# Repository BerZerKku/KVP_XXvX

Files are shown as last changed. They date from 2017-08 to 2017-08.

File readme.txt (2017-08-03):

Плата KVP
Сделана в OrCAD 16.6-2015-S073.

///////
03v5
Предназначена для использования в ОПТИКЕ и АВАНТах К400, РЗСК, Р400М сделанными в новом варианте. Используется совместно с BVP не ранее 04v2, если не нужна цифровая ретрансляция. И не ранее 04v3 если нужна.

Изменения:
Исправлены контактные площадки на супрессорах.
Дискретные входы сделаны с возможностью выбора перемычками 24/110/220В.

Код ПП: 3.140.490
Код КВП К400 : 2.140.808 (РЗСК)
Код КВП Р400 : 2.140.xxx
Код КВП Р400М: 2.140.xxx

Стэк:
35мкм  TOP 
1.5мм e=4.1 FR-4
35мкм  BOTTOM

Вариант Р400М:
отсутствуют: цифровая ретрансляция, выходы ком.ПРД/ПРМ, вход ПУСК, выход "Предупреждение".

Вариант Р400:
отсутствуют: цифровая ретрансляция, выходы ком.ПРД/ПРМ, вход ПУСК

Вариант К400 (РЗСК):
плата запаивается полностью.

//////
03v4
Предназначена для использования в ОПТИКЕ и АВАНТах К400, РЗСК, Р400М сделанными в новом варианте. Используется совместно с BVP не ранее 04v2, если не нужна цифровая ретрансляция. И не ранее 04v3 если нужна.

Изменения:
Добавлены дополнительные переключатели на ЛС/ТМ для выбора 485/422 интерфейса. При этом в 422 интерфейсе выход начинает работать полноценно, в 485 лог.1 формируется за счет подтяжек. 
Подтяжки на 485/422 интерфейсе перенесены на входы A/B и их номинал изменен с 470 Ом на 270 Ом. 
Последовательные защитные резисторы на интефейсах изменены с 10 на 5.1 Ом.
Разъем DIN изменен на 3-х рядный.

Код ПП: 3.140.015
Код ПП в сборе: 2.140.174

Стэк:
18мкм  TOP 
1.5мм e=4.5 FR-4
18мкм  BOTTOM

Основной вариант (Р400М):
отсутствуют: цифровая ретрансляция, выходы ком.ПРД/ПРМ, вход ПУСК, выход "Предупреждение".

Вариант Р400:
добавлен выход "Предупреждение"

Вариант К400 (РЗСК):
плата запаивается полностью.

////
03v3
Предназначена для использования в ОПТИКЕ и АВАНТах К400, РЗСК, Р400М 
сделанными в новом варианте.
Используется совместно с BVP не ранее 04v2, если не нужна цифровая
ретрансляция. И не ранее 04v3 если нужна.

Изменения:
Переделана цивровая ретрансляция. Сделан чистый 422 интерфейс и добавлен
сигнал управления.
Терминаторы 120 и 51Ом изменены на 240Ом.

Основной вариант (Р400М):
отсутствуют: цифровая ретрансляция, выходы ком.ПРД/ПРМ, вход ПУСК.

Вариант Р400:
добавлен выход "Предупреждение"

Вариант К400 (РЗСК):
плата запаивается полностью.

Недостатки:
Резисторы подтяжки стоят на выводах X/Y, что при переключении на 422 убирает
подтяжки с выводов A/B и оставляет вход 422 интерфейса без подтяжки. 
Вообще дуплекс/полудуплекс сделан хреново.
Место резисторов можно поставить предохранители.

!!!
На данный момент входы управления запаиваются только под 24.
Номиналы резисторов для других напряжений см. в РЭ.
!!!

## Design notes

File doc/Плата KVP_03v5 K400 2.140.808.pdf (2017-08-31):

п.5

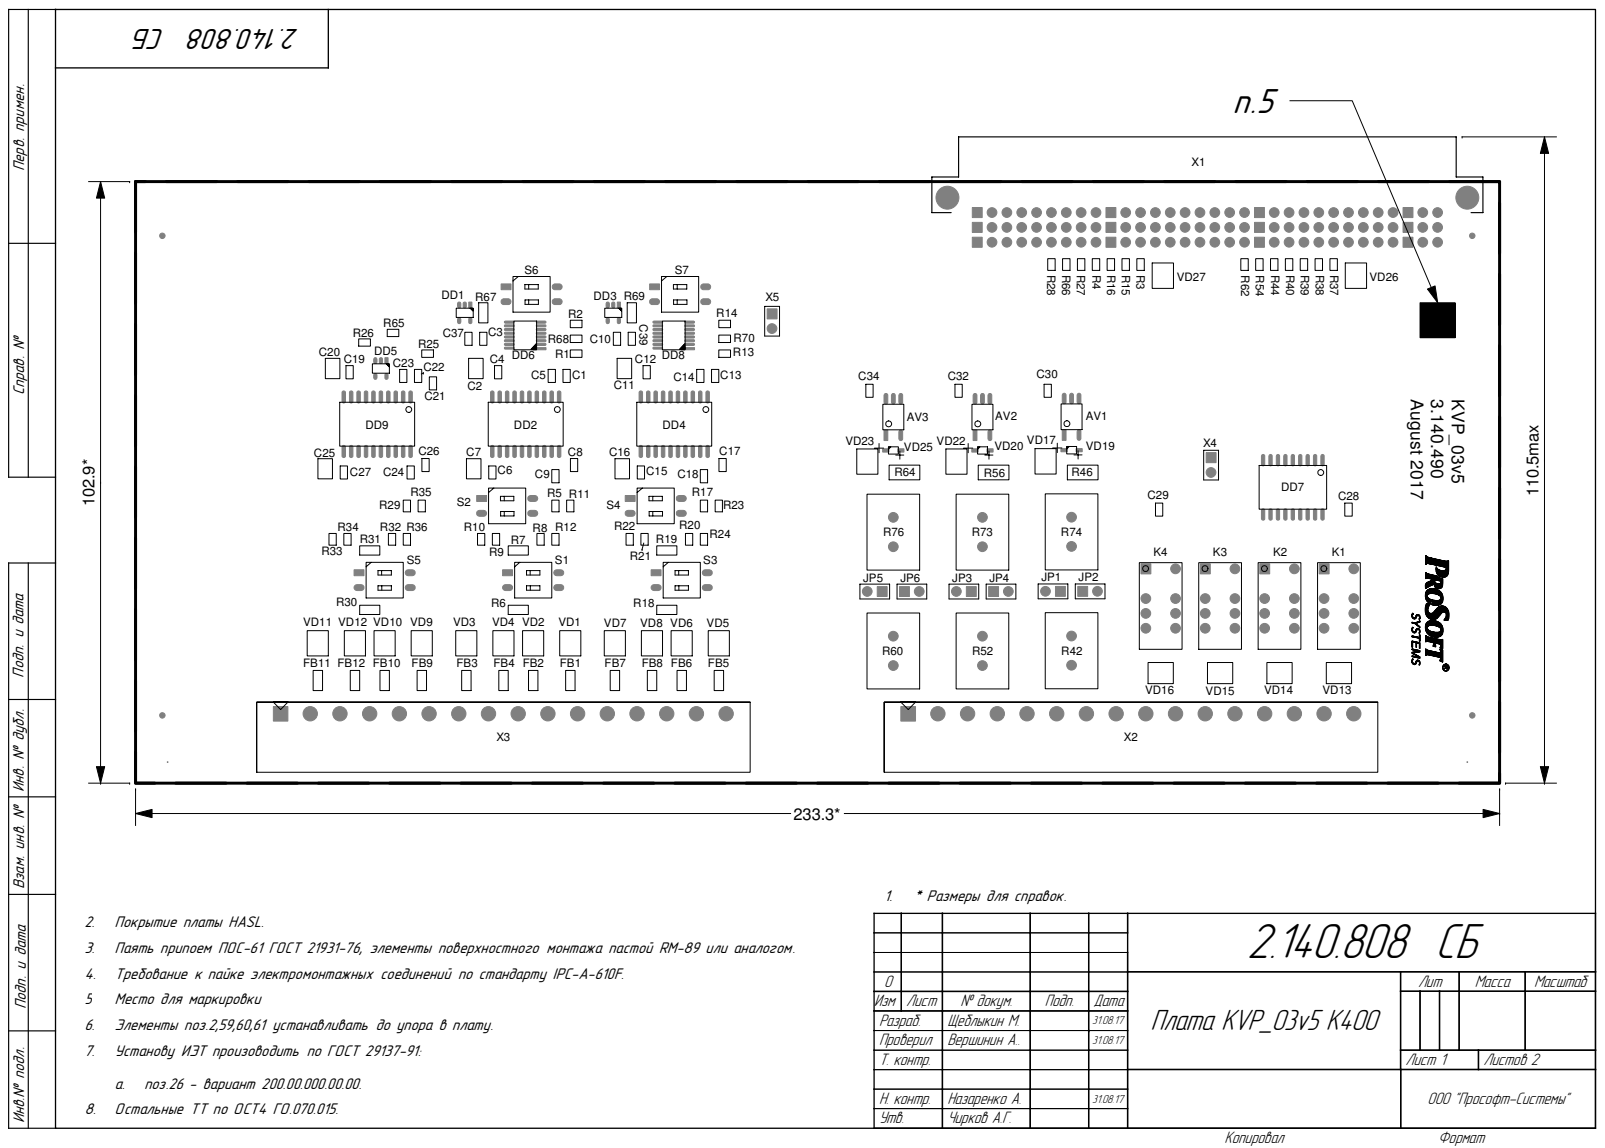
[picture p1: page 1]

Инв.№ подл. Подп. и дата Взам. инв. № Инв. № дубл. Подп. и дата Справ. № Перв. примен. R60 R52 R46

2. Покрытие платы HASL.
3. Паять припоем ПОС-61 ГОСТ 21931-76, элементы поверхностного монтажа пастой RM-89 или аналогом.
4. Требование к пайке электромонтажных соединений по стандарту IPC-A-610F.
5 Место для маркировки
6. Элементы поз.2,59,60,61 устанавливать до упора в плату.
7. Установу ИЭТ произоводить по ГОСТ 29137-91:

0 | | | | | Ïëàòà KVP_03v5 K400 | Ëèò | Ìàññà | Ìàñøòàá
Èçì | Ëèñò | ¹ äîêóì. | Ïîäï. | Äàòà
Ðàçðàá. | | Ùåáëûêèí Ì. | | 31.08.17
Ïðîâåðèë | | Âåðøèíèí À.. | | 31.08.17
Ò. êîíòð. | | | | | Ëèñò 1 | Ëèñòîâ 2

a. поз.26 - вариант 200.00.000.00.00.
8. Остальные ТТ по ОСТ4 ГО.070.015.

Í. êîíòð. | Íàçàðåíêî À. | 31.08.17
Óòâ. | ×èðêîâ À.Ã.

ÎÎÎ "Ïðîñîôò-Ñèñòåìû"

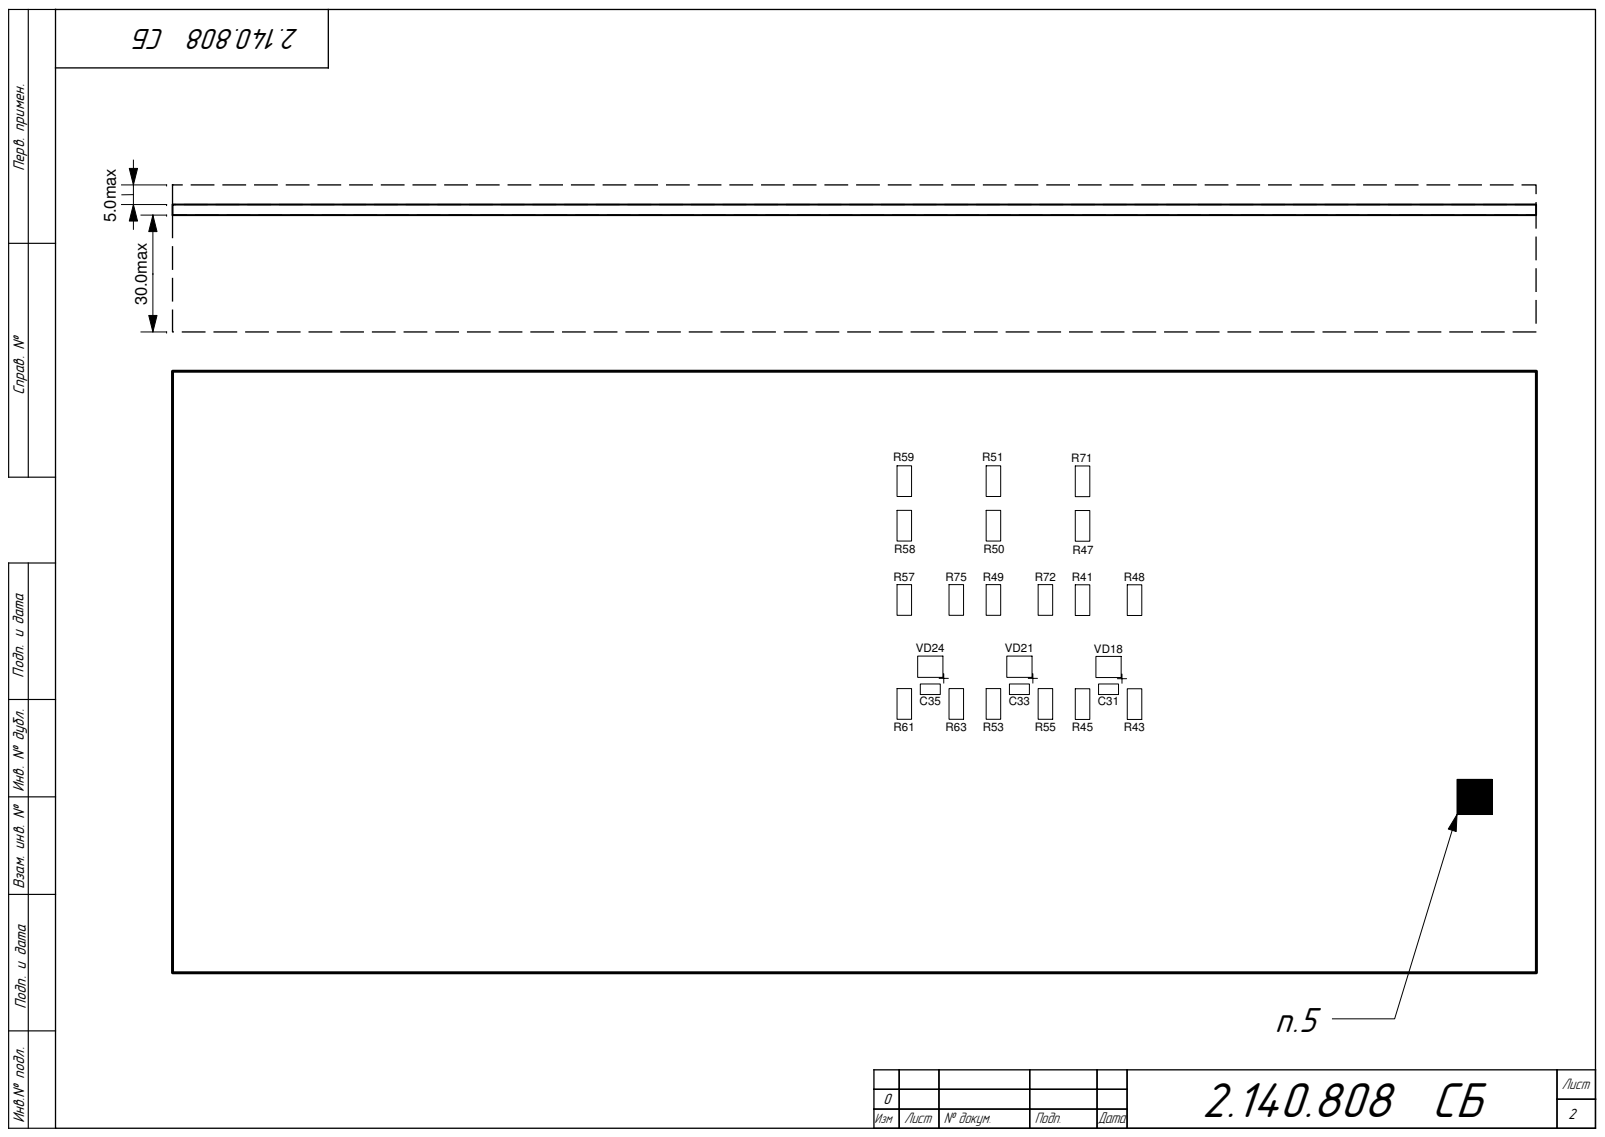
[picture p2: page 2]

Инв.№ подл. Подп. и дата Взам. инв. № Инв. № дубл. Подп. и дата Справ. № Перв. примен.

Напечатано: 31 августа 2017 г. 11:40:04, Щеблыкин Михаил Владимирович
Поз. | Наименование | Корпус | Кол. | Поз. по Э3 | Примечание
| Детали
1 | [3.140.490] Печатная плата KVP_03v5 | | 1
| Прочее
| Реле
2 | [G6S224DC] Реле G6S224DC 24VDC 2 Form C 0.5A/125VAC Omron | DIP8 | 4 | K1-K4
| Конденсаторы
6 | [0805-X7R-50V-0.1u F-10%] [+]Чип-конденсатор 0805 X7R 50V 0.1uF 10% | 0805 | 22 | C1, C3, C4, C6, C9, C10, C12, C13, C15, C18, C19, C21, C22, C24, C27-C30, C32, C34, C37, C39
7 | [1210-X7R-25V-10uF -10%] [+] Чип-конденсатор 1210 X7R 25V 10uF 10% | 1210 | 6 | C2, C7, C11, C16, C20, C25
8 | [0805-X7R-50V-0.01 uF-10%] Чип-конденсатор 0805 X7R 50V 0.01uF 10% | 0805 | 6 | C5, C8, C14, C17, C23, C26
9 | [1206-X7R-50V-0.1u F-10%] Чип-конденсатор 1206 X7R 50V 0.1uF 10% | 1206 | 3 | C31, C33, C35
| Дроссели, фильтры, катушки индуктивности
15 | [BLM31PG601SN1] Ферритовый фильтр BLM31PG601SN1 600Ом 1.5А 1206 Murata | 1206 | 12 | FB1-FB12

2.140.808

| Лист | № докум | Подп. | Дата
Разраб. | Щеблыкин М.В. | | 01.08.2017 | Плата KVP_03v5 K400 (Плата KVP_03v5 K400) | Лит. | Лист | Листов
Провер. | Вершинин А.С. | | 01.08.2017 | | | 1 | 5
Т.контр. | Бокова Т.И. | | 01.08.2017 | | Прософт-Системы
Н.контр. | Назаренко А.Н. | | 01.08.2017
Утв. | Чирков А.Г. | | 01.08.2017

| Резисторы
19 | [0805-10K-5%] Чип-резистор 0805 10K 5% | 0805 | 9 | R1, R2, R13, R14, R25, R26, R65, R68, R70
20 | [0805-100-5%] Чип-резистор 0805 100 5% | 0805 | 7 | R3, R4, R15, R16, R27, R28, R66
21 | [0805-5.1-5%] Чип-резистор 0805 5.1 5% | 0805 | 12 | R5, R8-R10, R17, R20-R22, R29, R32-R34
22 | [1206-240-5%] Чип-резистор 1206 240 5% | 1206 | 6 | R6, R7, R18, R19, R30, R31
23 | [0805-270-5%] Чип-резистор 0805 270 5% | 0805 | 6 | R11, R12, R23, R24, R35, R36
24 | [0805-6.2K-5%] Чип-резистор 0805 6.2K 5% | 0805 | 4 | R37-R40
25 | [2010-240-5%] Чип-резистор 2010 240 5% | 2010 | 6 | R41, R48, R49, R57, R72, R75
26 | [SQM-5W-5.1K-5%] Резистор SQM-5W 5.1K 5% | LEAD-2 | 6 | R42, R52, R60, R73, R74, R76
27 | [2010-300-5%] Чип-резистор 2010 300 5% | 2010 | 6 | R43, R45, R53, R55, R61, R63
28 | [0805-2K-5%] Чип-резистор 0805 2K 5% | 0805 | 3 | R44, R54, R62
29 | [2010-100-5%] Чип-резистор 2010 100 5% | 2010 | 3 | R46, R56, R64
30 | [2010-560-5%] Чип-резистор 2010 560 5% | 2010 | 3 | R47, R50, R58
31 | [2010-510-5%] Чип-резистор 2010 510 5% | 2010 | 3 | R51, R59, R71
32 | [1206-0] Чип-резистор 1206 0 | 1206 | 2 | R67, R69

2.140.808

Лист

2 Изм | Лист | № докум | Подп. | Дата

| Микросхемы
38 | [ACPL-M50L-500E] Микросхема | SO5 | 3 | AV1-AV3
| ACPL-M50L-500E SO5 Avago
39 | [SN74LVC1G14DBV] Микросхема SN74LVC1G14DBV SOT23-5 TI | SOT23-5 | 3 | DD1, DD3, DD5
40 | [ADM2587EBRWZ] Микросхема ADM2587EBRWZ SOICW20 AD (level:3) | SOICW2 0 | 3 | DD2, DD4, DD9
41 | [IDTQS3257QG] Микросхема IDTQS3257QG QSOP16 IDT | QSOP16 | 2 | DD6, DD8
42 | [ULN2803ADW] Микросхема ULN2803ADW SOIC18 TI | SOIC18 | 1 | DD7
| Диоды,светодиоды,супрессоры,стабилитроны
46 | [SM6T6V8CA] Диод SM6T6V8CA SMB STM | SMB(DO -214 | 13 | VD1-VD12, VD27
47 | [P6SMB300CA] Диод P6SMB300CA | SMB(DO -214 | 4 | VD13-VD16
48 | [SM6T6V8A] Диод SM6T6V8A SMB STM | SMB(DO -214 | 3 | VD17, VD20, VD23
49 | [SM6T18A] Диод SM6T18A | SMB(DO -214 | 3 | VD18, VD21, VD24
50 | [1N4148WS] Диод 1N4148WS SOD-323 | SOD323 | 3 | VD19, VD22, VD25
51 | [SM6T30CA] Диод SM6T30CA DO-214AA | SMB(DO -214 | 1 | VD26
| Переключатели, тумблеры
55 | [SmWDL-02] Переключатель SmWDL-02 | SMD4 | 7 | S1-S7
| Соединители
59 | [PLS-40] Разъем PLS-40 | 2 | 8 | JP1-JP6, X4, X5
| | | | 3 Изм
Лист | № докум | Подп. | Дата

60 | [09031966921] Соединитель, вилка DIN41612-C96MS-C1A -2 | DIN96 | 1 | X1
61 | [231-576/001-000] Вилка 1,2X1,2 шаг 5,08 мм (50 шт) | 16 | 2 | X2, X3
| | | | 4 Изм
Лист | № докум | Подп. | Дата

Лист регистрации ревизий

№ ревизии | № замененных (измененных) страниц | Дата ревизии | Краткое содержание и причина внесения изменений | Примечание
0 | вновь | 01.08.17

2.140.808

5

Лист Изм. | Лист | № докум. | Подп. | Дата

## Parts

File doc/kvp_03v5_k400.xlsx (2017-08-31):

 |  |  |  |  | Capture CIS Standard Bill Of Materials - Compressed Report
 |  |  |  |  |  | Report Created on Tuesday Aug 08 13:48:24 2017
Part Number | Description | Quantity | Ед. изм | Part Reference | Element Type | Case | Addition | Analogue
ACPL-M50L-500E | Микросхема ACPL-M50L-500E SO5 Avago | 3 | 0 | AV1-AV3 | Микросхемы | SO5
0805-X7R-50V-0.1uF-10% | [+]Чип-конденсатор 0805 X7R 50V 0.1uF 10% | 22 | 0 | C1,C3,C4,C6,C9,C10,C12,C13,C15,C18,C19,C21,C22,C24,C27-C30,C32,C34,C37,C39 | Конденсаторы | 0805
1210-X7R-25V-10uF-10% | [+] Чип-конденсатор 1210 X7R 25V 10uF 10% | 6 | 0 | C2,C7,C11,C16,C20,C25 | Конденсаторы | 1210
0805-X7R-50V-0.01uF-10% | Чип-конденсатор 0805 X7R 50V 0.01uF 10% | 6 | 0 | C5,C8,C14,C17,C23,C26 | Конденсаторы | 0805
1206-X7R-50V-0.1uF-10% | Чип-конденсатор 1206 X7R 50V 0.1uF 10% | 3 | 0 | C31,C33,C35 | Конденсаторы | 1206
SN74LVC1G14DBV | Микросхема SN74LVC1G14DBV SOT23-5 TI | 3 | 0 | DD1,DD3,DD5 | Микросхемы | SOT23-5
ADM2587EBRWZ | Микросхема ADM2587EBRWZ SOICW20 AD (level:3) | 3 | 0 | DD2,DD4,DD9 | Микросхемы | SOICW20
IDTQS3257QG | Микросхема IDTQS3257QG QSOP16 IDT | 2 | 0 | DD6,DD8 | Микросхемы | QSOP16 |  | N000353503
ULN2803ADW | Микросхема ULN2803ADW SOIC18 TI | 1 | 0 | DD7 | Микросхемы | SOIC18 |  | ULN2803AFWG
BLM31PG601SN1 | Ферритовый фильтр BLM31PG601SN1 600Ом 1.5А 1206 Murata | 12 | 0 | FB1-FB12 | Индуктивность | 1206
09031966921 | Соединитель, вилка DIN41612-C96MS-C1A-2 | 3 | 0 | J? | Соединители | DIN96
PLS-2 | Разъем PLS-2 | 8 | 0 | JP1-JP6,X4,X5 | Соединители | 2 |  | N000351373
G6S224DC | Реле G6S224DC 24VDC 2 Form C 0.5A/125VAC Omron | 4 | 0 | K1-K4 | Реле | DIP8 |  | 1-1462034-4
0805-10K-5% | Чип-резистор 0805 10K 5% | 9 | 0 | R1,R2,R13,R14,R25,R26,R65,R68,R70 | Резисторы | 0805
0805-100-5% | Чип-резистор 0805 100 5% | 7 | 0 | R3,R4,R15,R16,R27,R28,R66 | Резисторы | 0805
0805-5.1-5% | Чип-резистор 0805 5.1 5% | 12 | 0 | R5,R8-R10,R17,R20-R22,R29,R32-R34 | Резисторы | 0805
1206-240-5% | Чип-резистор 1206 240 5% | 6 | 0 | R6,R7,R18,R19,R30,R31 | Резисторы | 1206
0805-270-5% | Чип-резистор 0805 270 5% | 6 | 0 | R11,R12,R23,R24,R35,R36 | Резисторы | 0805
0805-6.2K-5% | Чип-резистор 0805 6.2K 5% | 4 | 0 | R37-R40 | Резисторы | 0805
2010-240-5% | Чип-резистор 2010 240 5% | 6 | 0 | R41,R48,R49,R57,R72,R75 | Резисторы | 2010
SQM-5W-5.1K-5% | Резистор SQM-5W 5.1K 5% | 6 | 0 | R42,R52,R60,R73,R74,R76 | Резисторы | LEAD-2
2010-300-5% | Чип-резистор 2010 300 5% | 6 | 0 | R43,R45,R53,R55,R61,R63 | Резисторы | 2010
0805-2K-5% | Чип-резистор 0805 2K 5% | 3 | 0 | R44,R54,R62 | Резисторы | 0805
2010-100-5% | Чип-резистор 2010 100 5% | 3 | 0 | R46,R56,R64 | Резисторы | 2010
2010-560-5% | Чип-резистор 2010 560 5% | 3 | 0 | R47,R50,R58 | Резисторы | 2010
2010-510-5% | Чип-резистор 2010 510 5% | 3 | 0 | R51,R59,R71 | Резисторы | 2010
1206-0 | Чип-резистор 1206 0 | 2 | 0 | R67,R69 | Резисторы | 1206
SmWDL-02 | Переключатель SmWDL-02 | 7 | 0 | S1-S7 | Переключатели | SMD4
SM6T6V8CA | Диод SM6T6V8CA SMB STM | 13 | 0 | VD1-VD12,VD27 | Диоды | SMB(DO-214AA)
P6SMB300CA | Диод P6SMB300CA | 4 | 0 | VD13-VD16 | Диоды | SMB(DO-214AA)
SM6T6V8A | Диод SM6T6V8A SMB STM | 3 | 0 | VD17,VD20,VD23 | Диоды | SMB(DO-214AA)
SM6T18A | Диод SM6T18A | 3 | 0 | VD18,VD21,VD24 | Диоды | SMB(DO-214AA)
1N4148WS | Диод 1N4148WS SOD-323 | 3 | 0 | VD19,VD22,VD25 | Диоды | SOD323
SM6T30CA | Диод SM6T30CA DO-214AA | 1 | 0 | VD26 | Диоды | SMB(DO-214AA)
231-576/001-000 | Вилка 1,2X1,2 шаг 5,08 мм (50 шт) | 2 | 0 | X2,X3 | Соединители | 16

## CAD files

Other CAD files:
pcb/sop65p600x172-16.psm

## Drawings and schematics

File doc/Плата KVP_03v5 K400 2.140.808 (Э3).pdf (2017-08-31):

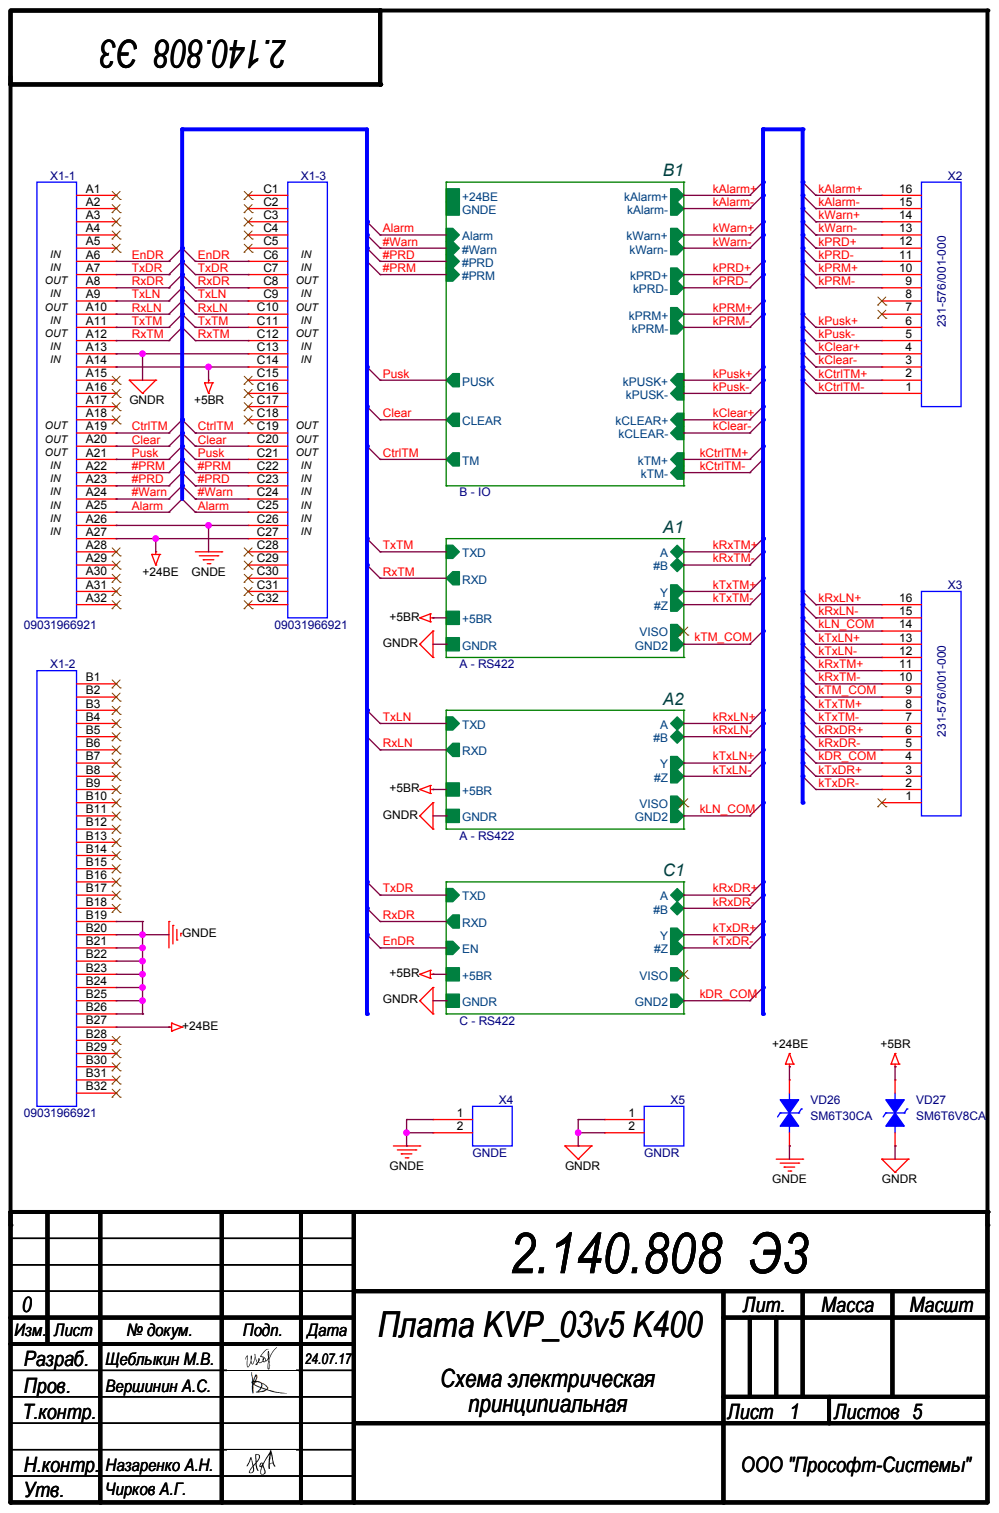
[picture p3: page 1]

0 | | | | | Плата KVP_03v5 K400 Плата KVP_03v5 K400 Плата KVP_03v5 K400 Схема электрическая Схема электрическая Схема электрическая | Лит. | Масса Масса Масса | Масшт Масшт Масшт
Изм. Изм. Изм. | Лист Лист Лист | № докум. № докум. № докум. | Подп. Подп. Подп. | Дата Дата Дата
Разраб. Разраб. Разраб. | | Щеблыкин М.В. Щеблыкин М.В. Щеблыкин М.В. | | 24.07.17 24.07.17 24.07.17
Пров. Пров. Пров. | | Вершинин А.С. Вершинин А.С. Вершинин А.С.
принципиальная Т.контр. принципиальная Т.контр. принципиальная Т.контр. | Лист Лист Лист 1 5 1 5 1 5 | Листов Листов Листов

Н.контр. Н.контр. Н.контр. | Назаренко А.Н. Назаренко А.Н. Назаренко А.Н.
Утв. Утв. Утв. | Чирков А.Г. Чирков А.Г. Чирков А.Г.

ООО "Прософт-Системы" ООО "Прософт-Системы" ООО "Прософт-Системы"

# Schematic Path = /A1

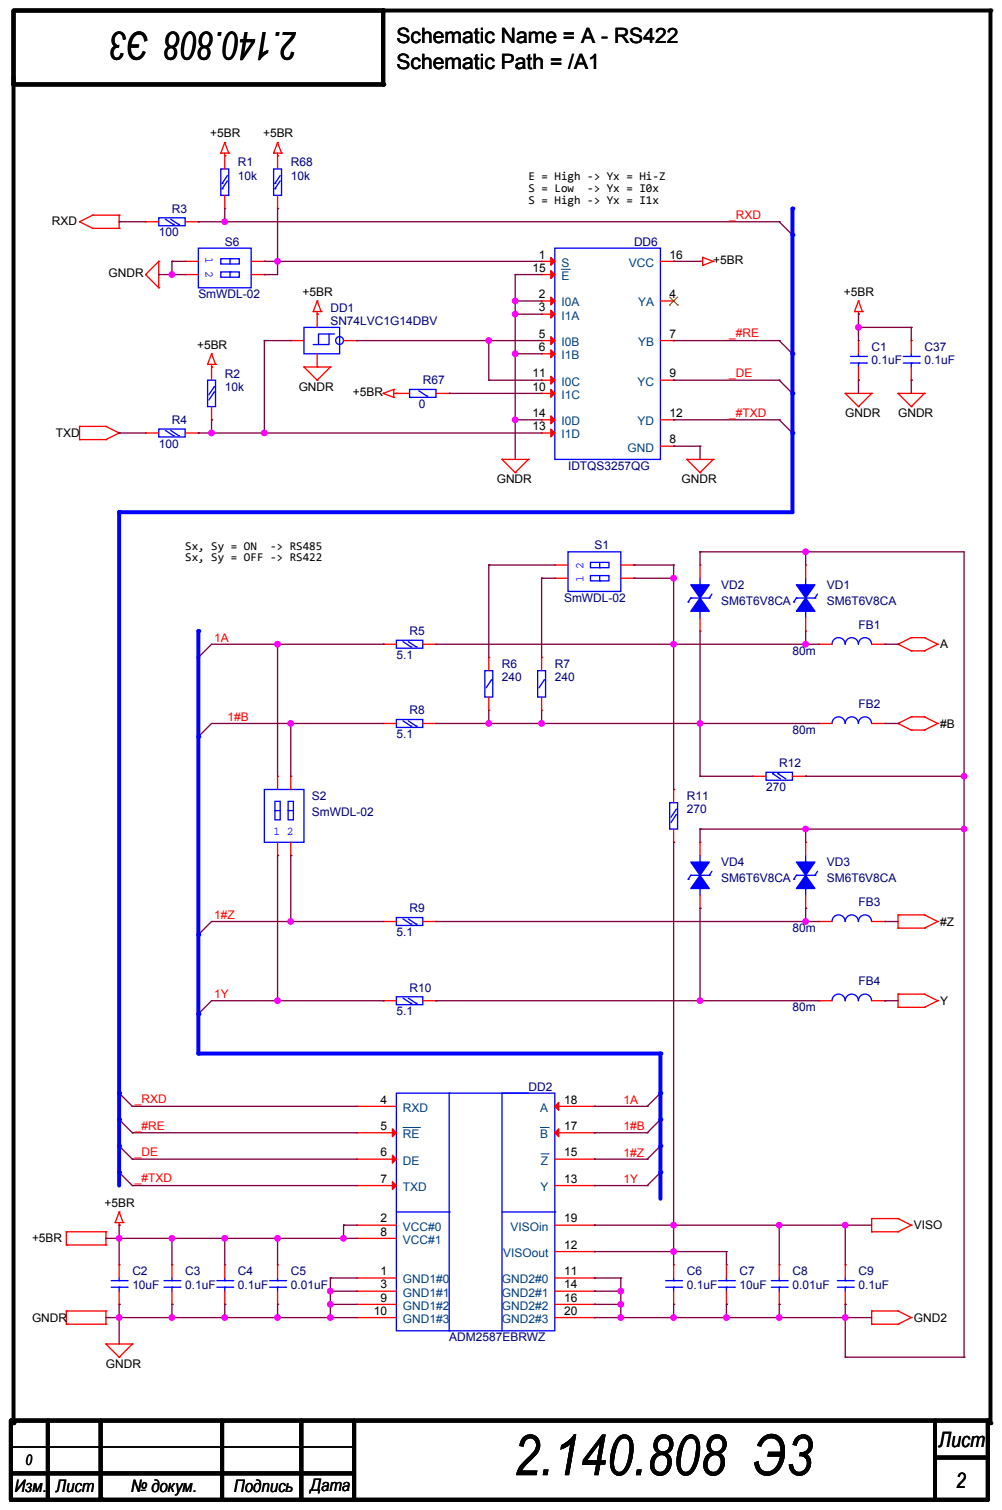
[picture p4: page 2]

Лист 2.140.808 Э3 Лист 2.140.808 Э3 Лист 2.140.808 Э3 2 2 2

Изм. | Лист | № докум. | Подпись | Дата

# Schematic Path = /A2

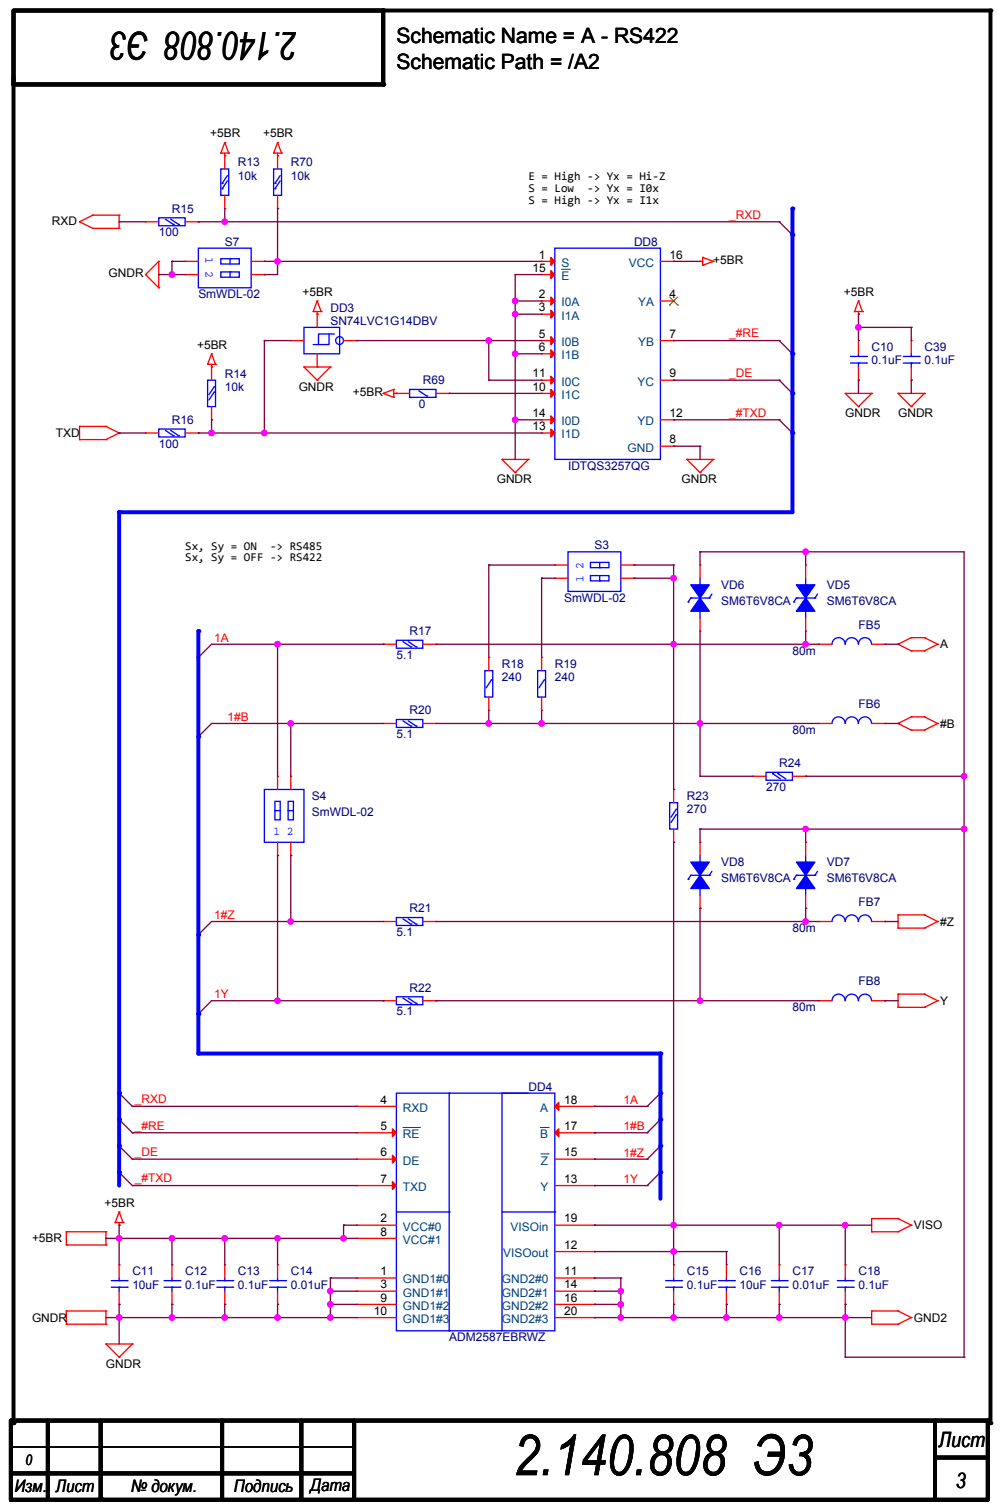
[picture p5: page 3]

# Schematic Path = /B1

K

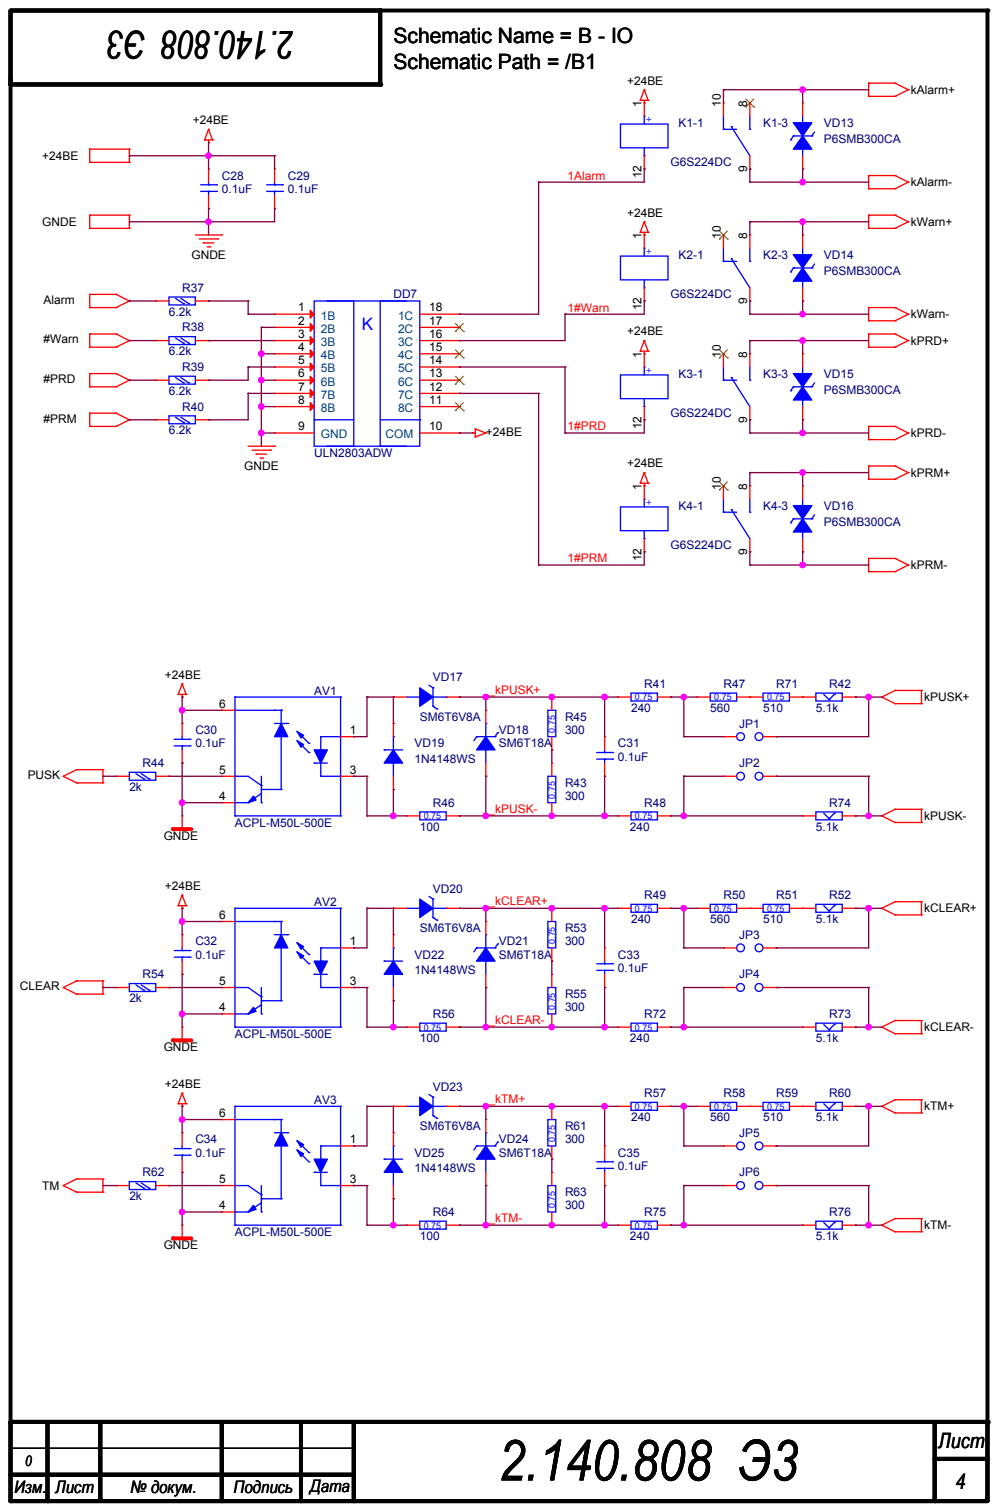
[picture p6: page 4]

# Schematic Path = /C1

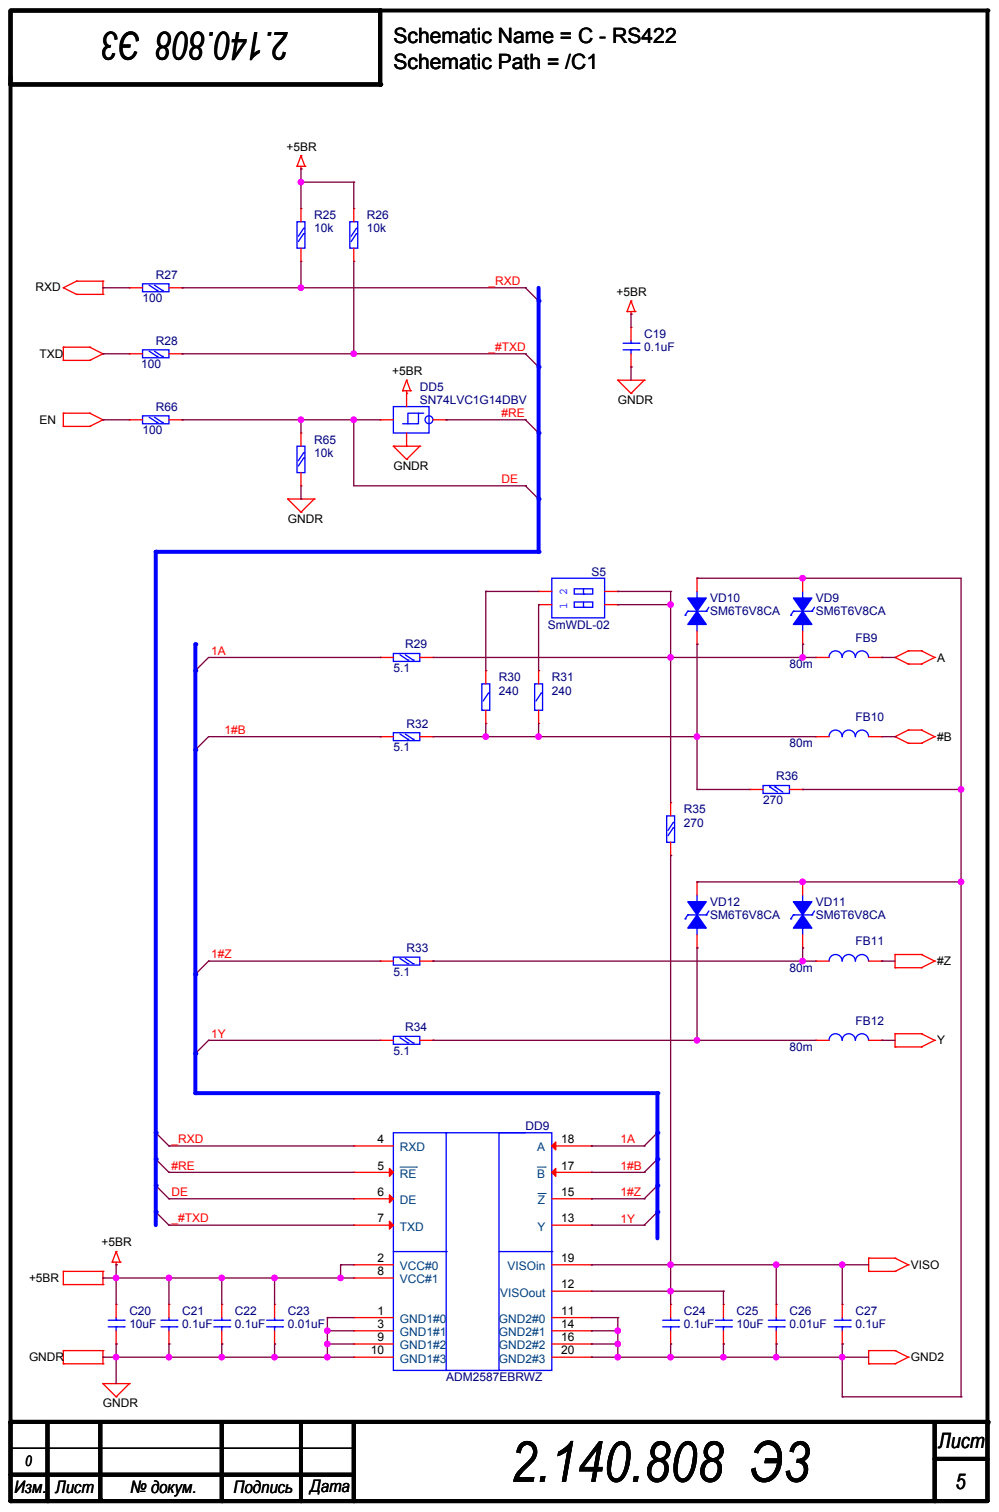
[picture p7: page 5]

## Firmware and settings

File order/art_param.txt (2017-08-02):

DEVICE-TYPE           GERBER_RS274X
OUTPUT-UNITS          MM
FILM-SIZE             2000000 3000000
FORMAT                3.4
ABORT-ON-ERROR        NO
SCALE                 1
SUPPRESS-LEAD-ZEROES  YES
SUPPRESS-TRAIL-ZEROES NO
SUPPRESS-EQUAL        YES
UNDEF-APT-CONT        NO

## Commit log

2015-12-14 Начата работа по переделки платы. Основные замечания: 1. Неправильные подтяжки на ТМ при работе по 422. Сейчас делается доработка. 2. Пороги срабатывания ДС.
    [KVP_03V4.DSN]
2015-12-14 Добавлен код ПП в файл описания.
2015-12-14 Началась перерисовка схемы элементами из ЦБ.
    [KVP_03V4.DSN]
2015-12-15 Часть элементов на схеме заменена на элементы ЦБ. Схема передана на плату, исправлены ошибки.
    [KVP_03V4.DSN, kvp_03v4.brd]
2015-12-15 Заменены разъемы на библиотечные.
    [KVP_03V4.DSN, kvp_03v4.brd]
2015-12-15 Изменены полигоны на ДВ.
    [KVP_03V4.DSN, kvp_03v4.brd]
2015-12-15 Начата переделка схемы под нормальный RS-422 / хреновый RS-485 для ЛС и ТМ.
    [KVP_03V4.DSN, kvp_03v4.brd]
2015-12-16 Закончена разводка. Началась прическа платы.
    [KVP_03V4.DSN, kvp_03v4.brd]
2015-12-16 Уменьшены номиналы последовательных резисторов в интерфейсах RS485/422 c 10 до 5.1 Ом. Уменьшены подтяжки в интерфейсах RS485/422 c 470 до 270 Ом и перекинуты на входы (A/B), вместо выходов (X/Y). Ча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
    [KVP_03V4.DSN, kvp_03v4.brd]
2015-12-16 Заменена еще часть элементов из ЦБ.
    [KVP_03V4.DSN, kvp_03v4.brd]
2015-12-17 Начато создание вариантных исполнений. Изменен корпус для QS3257, был с шагом 0.65, а надо 0.635 мм. Супрессоры 300BA поставлены P6SMB, т.к. закупаются именно они.
    [KVP_03V4.DSN, kvp_03v4.brd]
2015-12-17 Почищены мелкие недочеты на плате.
    [kvp_03v4.brd, sop65p600x172-16.psm]
2015-12-17 Сформирован слой шелкографии.
    [kvp_03v4.brd]
2015-12-17 Скруглены углы.
    [kvp_03v4.brd]
2015-12-17 Добавлено описание.
    [KVP_03V4.DSN, kvp_03v4.brd]
2015-12-17 Проверка работы коммита.
2016-02-19 Добавлена документация на плату.
2016-11-29 Сделаны гербера для паст, для этого подправлены несколько контактных площадок.
    [art_param.txt, kvp_03v4.brd, nc_param.txt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]
2017-07-27 Обновлены посадочные места для супрессоров. Входы переделаны для возможности установки рабочего напряжения. Начата замена элементов из ЦБ.
    [KVP_03V4.DSN, KVP_03V5.DSN, kvp_03v4.brd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]
2017-07-31 На схеме часть элементов заменена из ЦБ. (QS3257 - вывод 15 должен быть Е с инверсией). НА плате расставлена шелкография.
    [KVP_03V5.DSN]
2017-08-02 Добавлены файлы заказа. Обновлены резисторы 2010 и переключатели, на них была исправлена шелкография.
    [KVP_03V5.DSN, KVP_03v5 02.08.17.xls, art_param.txt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]
2017-08-02 В файле заказа исправлено название файла сверловки.
    [KVP_03v5 02.08.17.xls]
2017-08-02 В стэке слоев исправлена толщина меди на 35мкм.
2017-08-03 Начато создание документации для варианта К400.
    [KVP_03V5.DSN, kvp_03v5_k400.xlsx]
2017-08-31 Добавлен СБ. Исправлено оформление СП и Э3.
    [KVP_03V5.DSN, kvp_03v5_k400.xlsx]
2017-08-31 Добавлен объединенный файл СП+СБ.
